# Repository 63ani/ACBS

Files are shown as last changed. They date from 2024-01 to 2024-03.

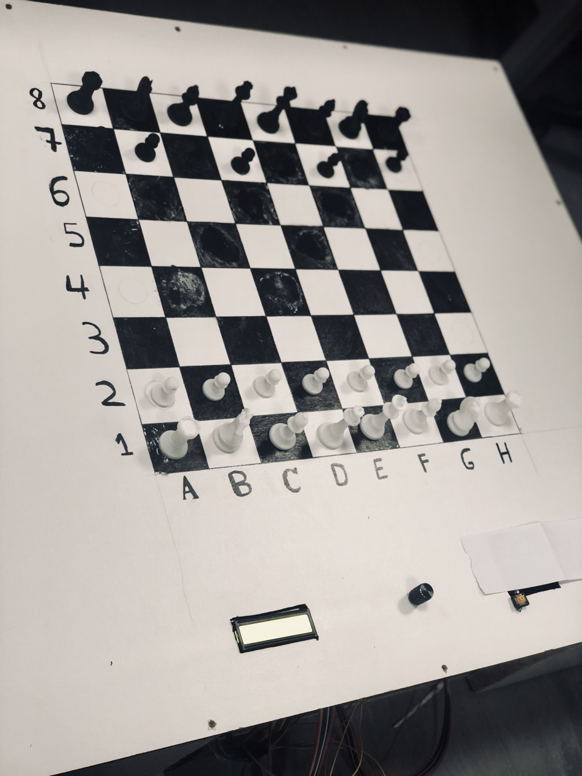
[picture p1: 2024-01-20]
ACBS Picture.jpg

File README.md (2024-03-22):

# Automated Chess Board System (ACBS)

## Introduction

The Automated Chess Board System (ACBS) revolutionizes the classic game of chess, allowing players to engage with an AI opponent while witnessing the game unfold on a physical chessboard. This system cleverly combines traditional chess with modern automation technology, translating digital strategies into physical movements on the chessboard.

## Table of Contents

- [Introduction](#introduction)
- [Theory](#theory)
- [Design](#design)
- [Installation](#installation)
- [Usage](#usage)
- [Contributing](#contributing)

## Theory

ACBS is powered by a valuation-based algorithm with a Minimax core, optimizing moves by evaluating piece values and positions. This sophisticated approach enables dynamic difficulty adjustments, making it suitable for various skill levels.

## Design

Featuring a blend of 3D-printed components and precision engineering, the ACBS design focuses on accuracy and efficiency. It employs NEMA17 stepper motors, DRV8825 drivers, and an ingenious system of limit switches and electromagnets for piece movement.

## Installation

Please refer to the detailed installation instructions provided on our GitHub repository to set up your ACBS.

## Usage

To start playing against the AI or watch the AI play against itself, follow the step-by-step guide on initializing the system and making moves.

## Contributing

We welcome contributions! If you're interested in improving ACBS.

For more detailed information about the Automated Chess Board System, including technical specifications and how to contribute, please contact me.

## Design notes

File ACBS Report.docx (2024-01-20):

Princess Sumaya University for Technology

King Abdullah II Faculty of Engineering

Electrical Engineering Department

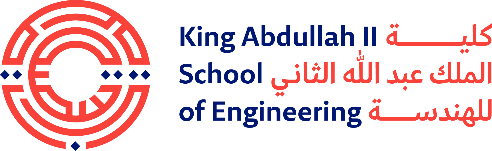
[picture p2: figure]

Embedded Systems 22442

Final Design Project

Automated Chess Board System

Authors: | | | Supervisor:
Laith Taani Osama Alfaqeeh Ahmad Alsayeh | 20200333 20200503 20200997 | Comp. Eng. NIS. NIS. | Dr. Belal Sababha

January 20, 2024

Abstract

The report details the process of designing of an Automated Chess Board System (ACBS) using PIC16F877A microcontroller to allow the interaction between physical chess play and digital strategy computation. The system utilizes stepper motors for piece movement and establishes serial communication for move execution. The programming is carried out in C for the microcontroller and Python for serial interactions. The focus of the investigation was to integrate mechanical components with software to autonomously play chess.

# 1 Introduction

Chess is an ancient strategy game in which you aim to move pieces strategically to defeat your opponents and finally checkmate them. We want to combine the time-tested chess techniques with automation technology with our Automated Chess Board System. Chess players now have a platform to practice and enjoy the game by competing against artificial intelligence (AI). Players may successfully develop their skills and view their strategies play across the board. It transforms commands into movements on an electronic chessboard.

## 1.1 Theory

The system is based on assigning values to pieces and positions to evaluate the best move possible. Each type of piece has a standard value: pawns are worth 1, knights and bishops 3, rooks 5, and queens 9. The king's value is set to 0 since it cannot be captured. The algorithm uses these values to calculate a score for the board at any given state, aiming to maximize the score for one player and minimize it for the other.

The decision-making process in the code uses a simplified version of the Minimax algorithm, selecting moves that lead to the highest possible score for the player while assuming the opponent will play perfectly to minimize that score.

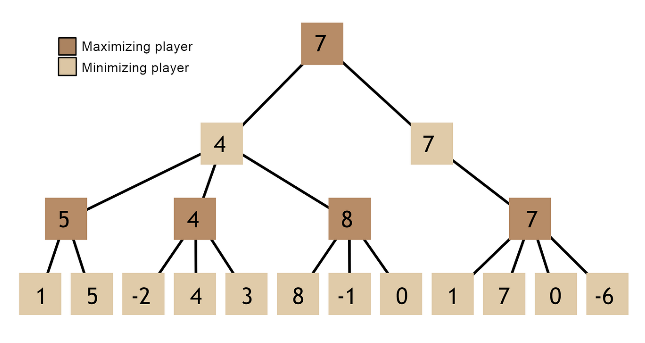
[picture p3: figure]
The Anatomy of a Chess AI. Chess-playing programs made their grand… | by April Walker | Medium

Expressed as: Max(P)=Score(P)-Score(O) , where P is the player and O is the opponent.

The algorithm evaluates all potential moves up to a certain depth and chooses the one with the best score after considering both the material and positional advantages. Changing the depth can be regarded as the level of the chess engine.

Figure 1 Minimax Algorithm

# 2 Design

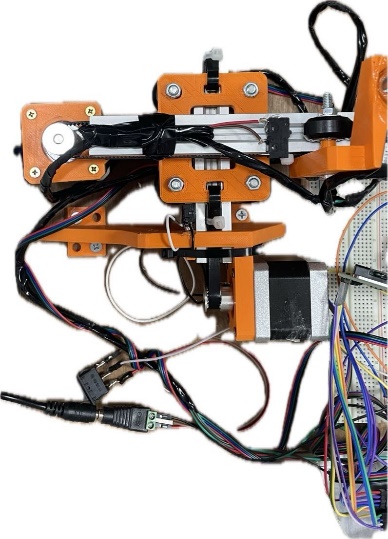
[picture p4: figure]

The design process for the Automated Chess Board System began with a detailed schematic design. This schematic served as a guide, detailing all electronic components and their connections. Then, each component went individual testing to ensure functionality. The NEMA17 stepper motors, were linked to DRV8825 drivers. These motors function by converting a negative edged step signal into precise 1.8-degree rotational movement.

Figure 2 X and Y Axes

The physical structure of the chessboard was then constructed using 3D-printed parts, attached to aluminum profiles and GT belts for the X and Y axes, with careful measurements to determine the correct size of the squares on the board.

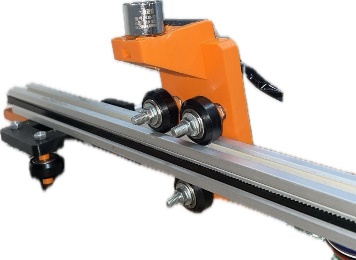
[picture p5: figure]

To ensure precise movements on the chessboard, limit switches were attached to define the 'home' position. Following this, an electromagnet was added for piece manipulation. The electromagnet was attached to a custom 3D-printed part and secured with a screw. Due to the 12V requirement for the electromagnet, it was connected through an NMOS transistor. Further tests were made to calibrate the chessboard, ensuring the movements executed by the electromagnet accurately corresponded to the designated chess squares.

Figure 3 Electromagnet

With the physical components in place, the system's code was developed to interpret and execute chess moves received via serial communication from a Python script. The received data contains information on the type of move and the specific board squares involved. The microcontroller's program was refined to respond accurately to the serial commands, translating them into the precise movements of the chess pieces on the board. This ensured that the Automated Chess Board System could react to the player's strategy as communicated through the Python interface, completing the integration of the hardware and software components.

# 3 Results and Discussions

The design and code for the Automated Chess Board System was functional in the movement of the magnet accurately. Nevertheless, the system's piece movement accuracy was approximately 80%. This was due to the magnet-to-board surface alignment and the variance in chess piece weights. The arrangement of the wiring also presented issues, occasionally disrupting piece movement. The initial code also posed a challenge due to its size (above 2K) which caused us to alter the design, were we had to remove the use of a keypad and depend on serial communication.

Possible fixes to the stated issues could include the use of a servo motor to control the position of the magnet accurately allowing it to be lowered when not needed. Another fix could be the use of a stronger magnet which allows to increase the distance between the magnet and the surface.

# 4 Conclusions

With an astounding 80% accuracy in piece movement, the Automated Chess Board System demonstrates the effective integration of artificial intelligence with mechanical chess. Further improvement is possible, especially in the area of magnet alignment.

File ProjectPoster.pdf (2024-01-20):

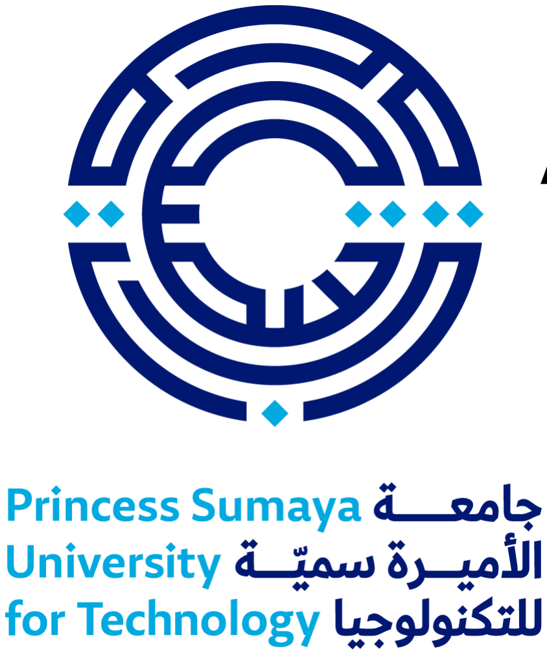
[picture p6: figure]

# Automated Chess Board System

# Introduction

Chess is an ancient strategy game in which you aim to move pieces strategically to defeat your opponents and finally checkmate them. We want to combine the time-tested chess techniques with automation technology with our Automated Chess Board System. Chess players now have a platform to practice and enjoy the game by competing against artificial intelligence (AI). Players may successfully develop their skills and view their strategies play across the board. It transforms commands into movements on an electronic chessboard.

# Design

➢We used two drivers for two motors one on each axis, here’s a schematic for one of the motors

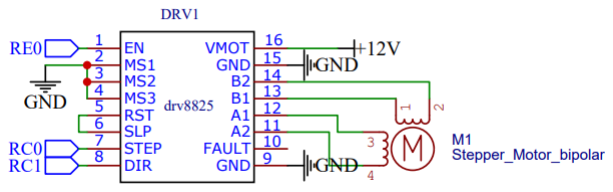
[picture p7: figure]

Figure 1: DRV8825 Driver, Nema 17 stepper motor. The NEMA17 stepper motors, were linked to DRV8825 drivers. These motors function by converting a negative edged step signal into precise 1.8-degree rotational movement.

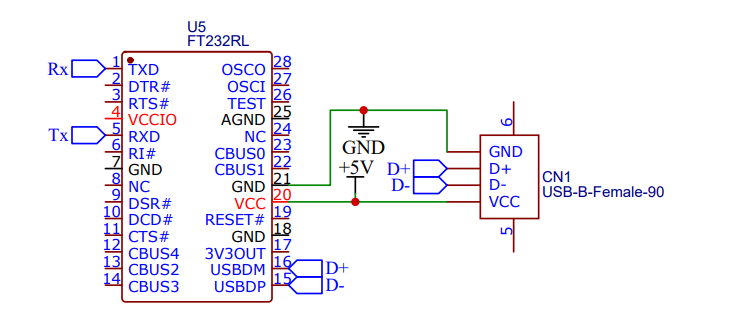
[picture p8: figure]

Figure 2: USB to serial chip DT23RL With the physical components in place, the system's code was developed to interpret and execute chess moves received via serial communication from a Python script. The received data contains information on the type of move and the specific board squares involved. The microcontroller's program was refined to respond accurately to the serial commands, translating them into the precise movements of the chess pieces on the board.

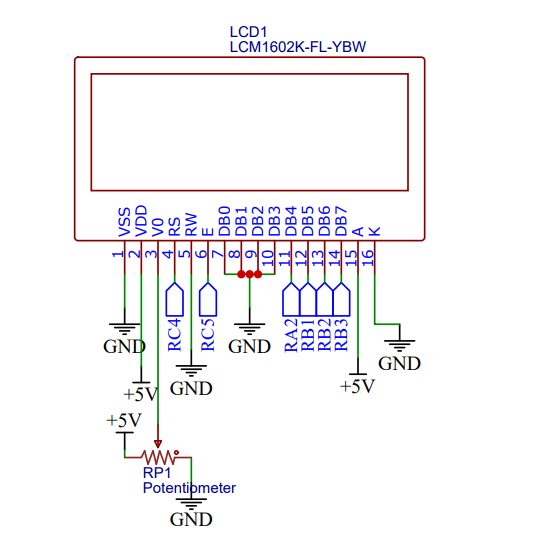
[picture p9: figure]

Figure 3: LCD Screen
The LCD screen provides real-time updates on the game's status, indicating whether it's currently the player's round or the bot's round. It also displays whether the game is in progress or waiting for the user to initiate it. Additionally, the difficulty level is seamlessly controlled through a potentiometer, allowing users to fine-tune the challenge to their preference before starting the game.

# Results

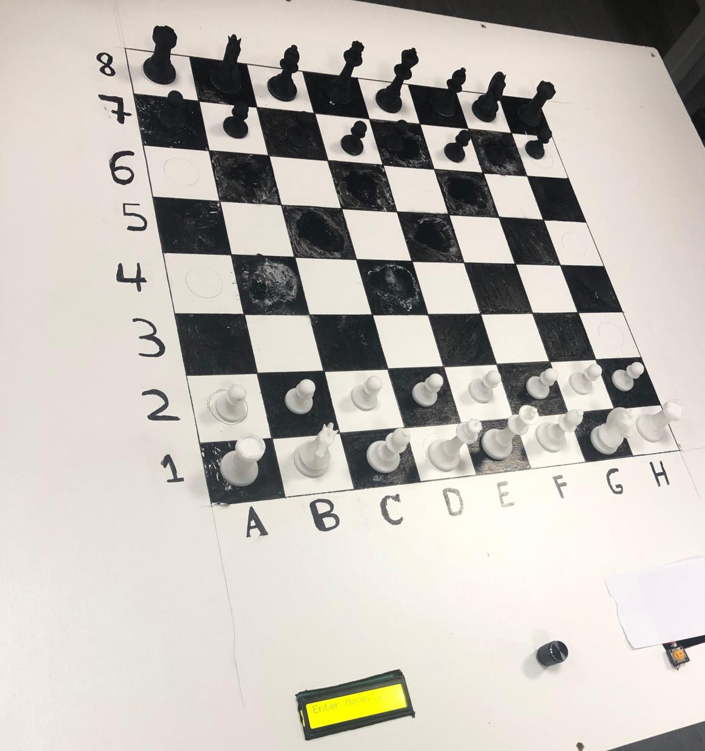
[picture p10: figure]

Figure 4: Chess Board

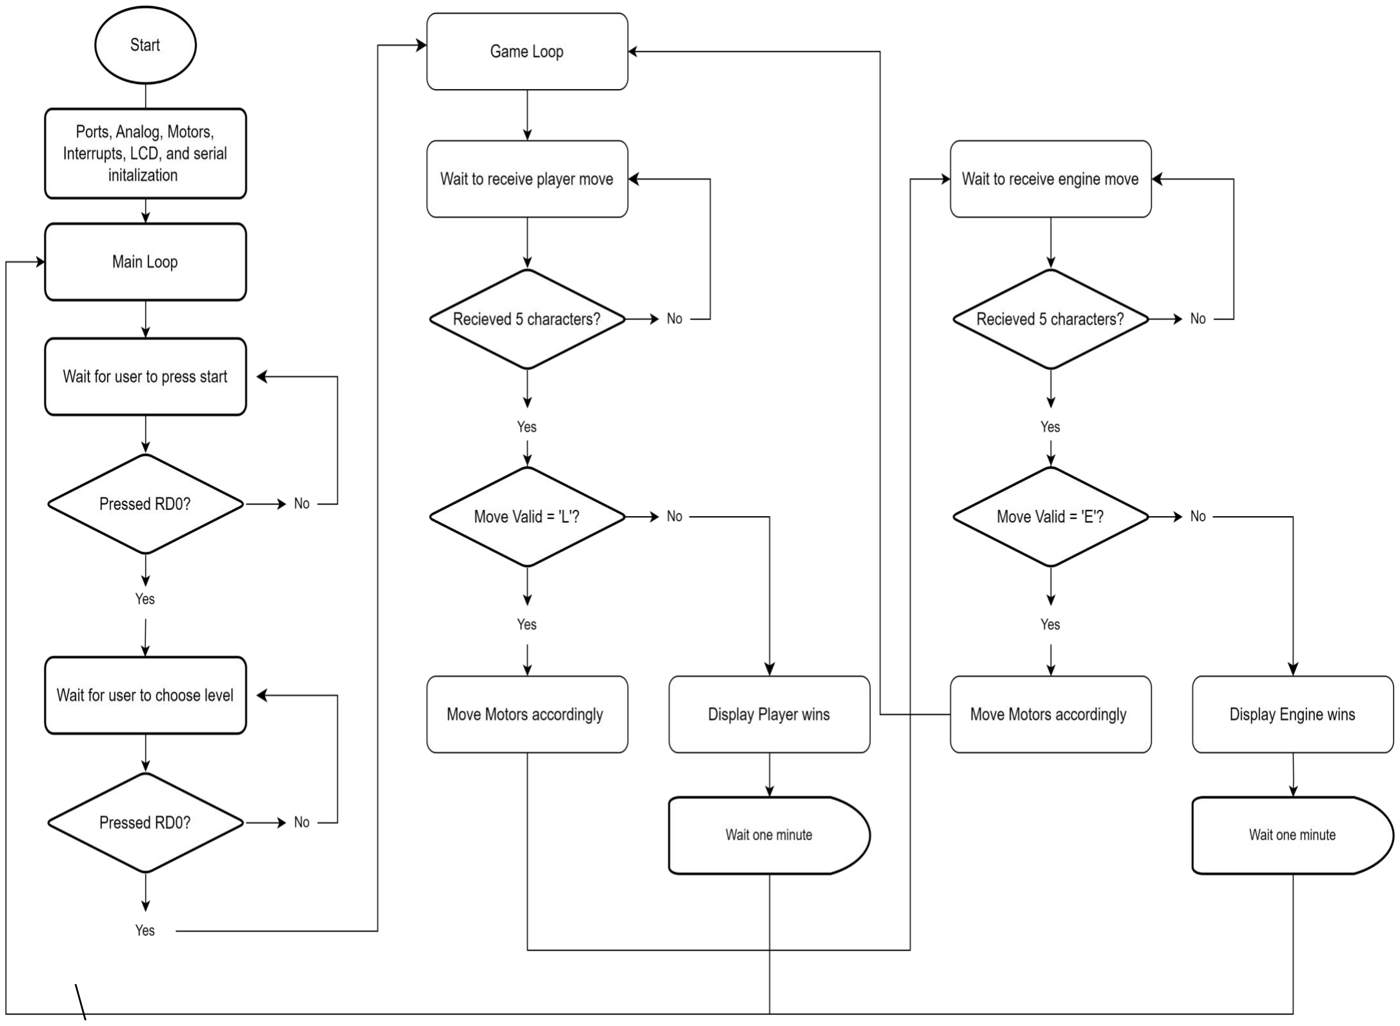
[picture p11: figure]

Figure 5: Software flowchart

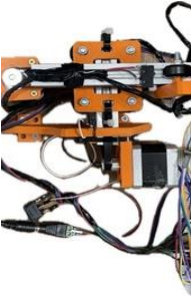
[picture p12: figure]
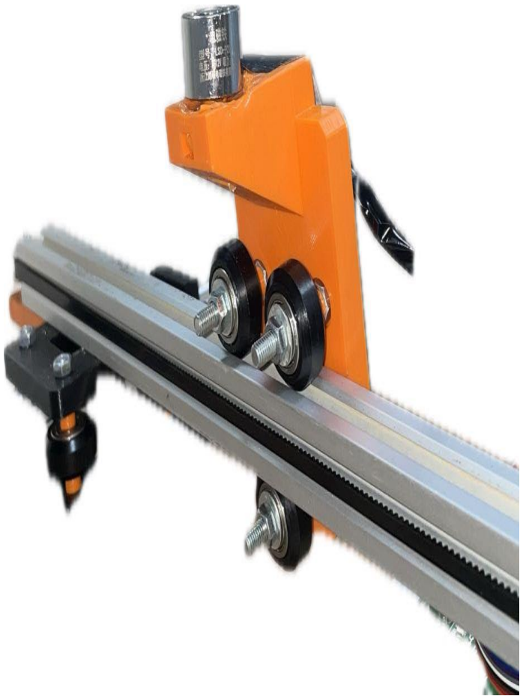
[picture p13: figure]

(a) (b)

Figure 6: (a) ) X and Y Axes , (b) Electromagnet

The physical structure of the chessboard was constructed using 3D-printed parts, attached to aluminum profiles and GT belts for the X and Y axes.
Electromagnet was added for piece manipulation. The electromagnet was attached to a custom 3D-printed part.

# Conclusion

With an astounding 80% accuracy in piece movement, the Automated Chess Board System demonstrates the effective integration of artificial intelligence with mechanical chess. Further improvement is possible, especially in the area of magnet alignment.

## L. Taani, O. Al-Faqeh, A. Al-Sayeh Supervisor: Dr. Belal Sababha Embedded Systems Final Design Project, Fall 2023 King Abdullah II School of Engineering Princess Sumaya University for Technology

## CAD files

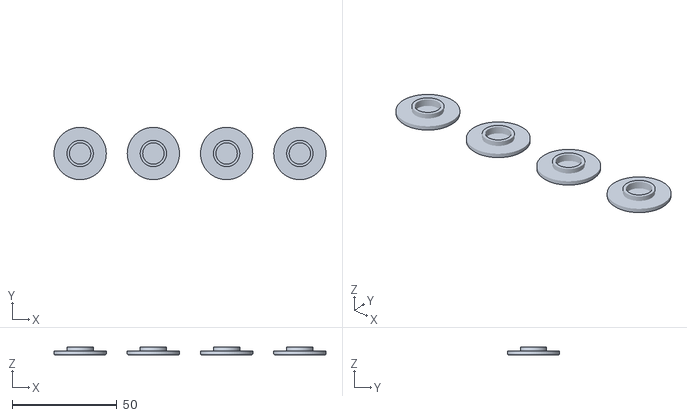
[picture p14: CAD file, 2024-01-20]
3D Prints/_Chess_Pieces15_LG_BASEx4.stl
130.0 x 25.0 x 4.00

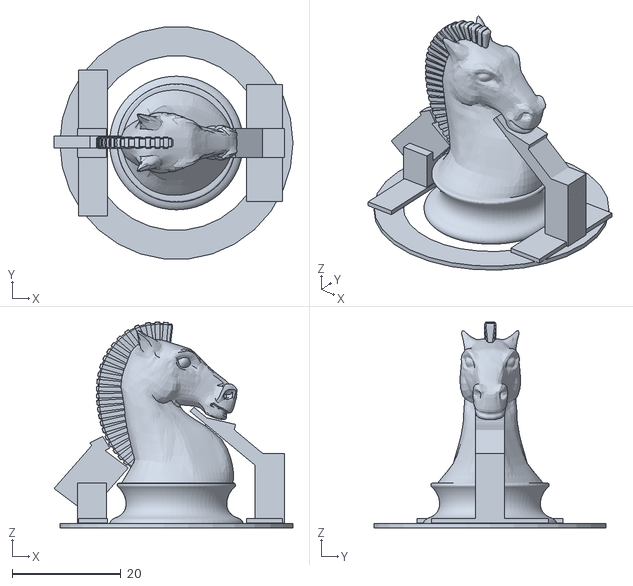
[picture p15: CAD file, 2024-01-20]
3D Prints/_Chess_Pieces15_KNIGHT.stl
43.9 x 42.6 x 37.9

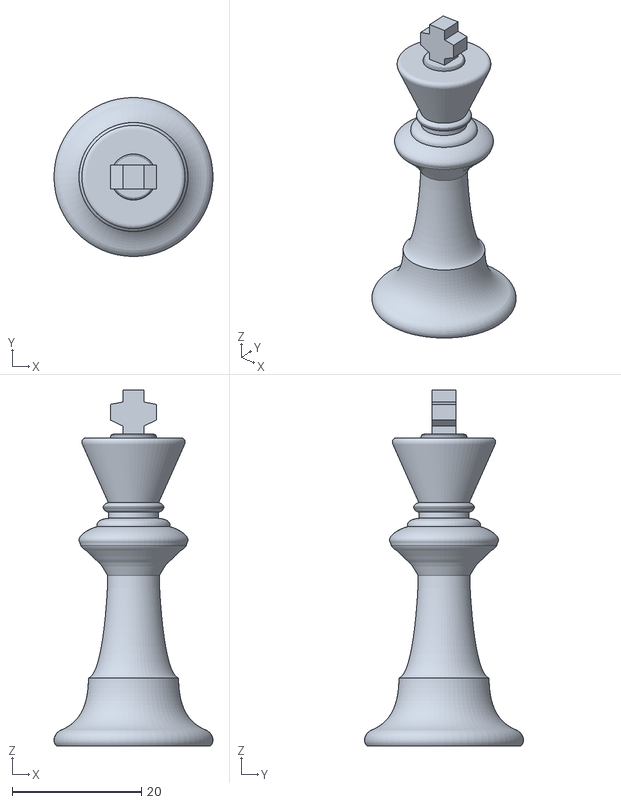
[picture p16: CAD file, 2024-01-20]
3D Prints/_Chess_Pieces15_KING.stl
24.6 x 24.6 x 55.1

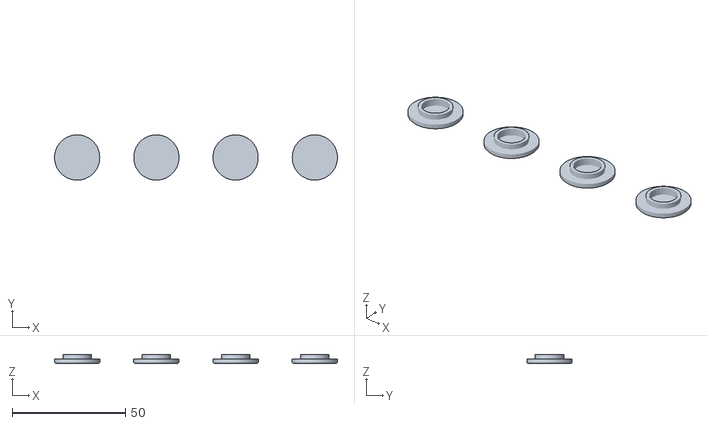
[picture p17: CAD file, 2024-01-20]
3D Prints/_Chess_Pieces15_SM_BASEx4.stl
125.0 x 20.0 x 4.00

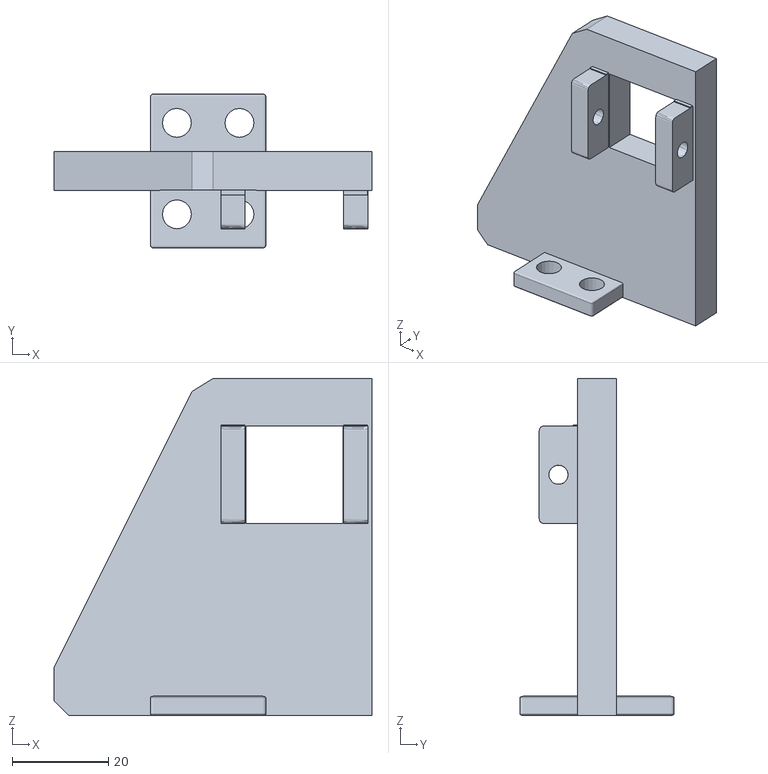
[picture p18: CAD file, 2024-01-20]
3D Prints/side1.stl
66.0 x 32.0 x 70.0

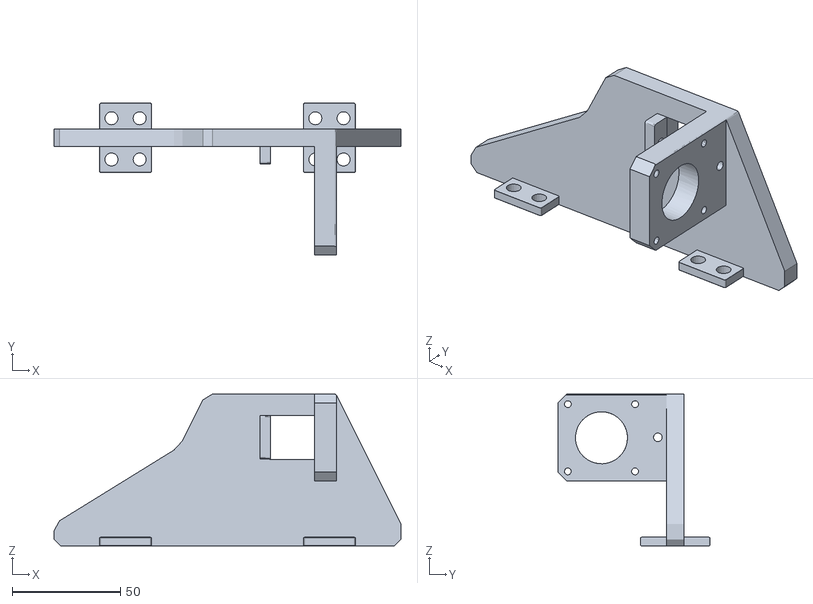
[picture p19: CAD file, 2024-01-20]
3D Prints/Y_axis Motor.stl
160.0 x 70.0 x 70.0

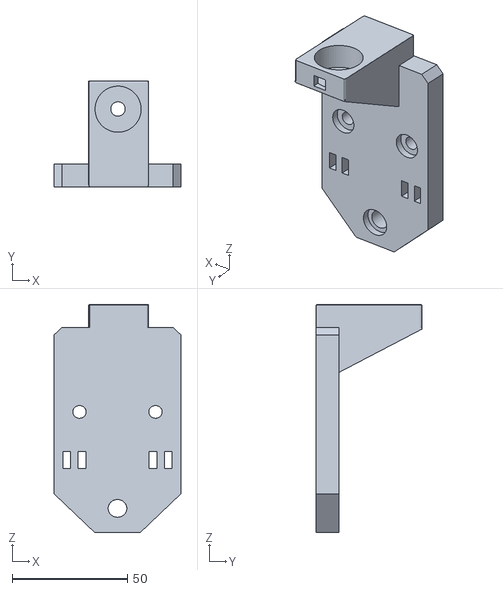
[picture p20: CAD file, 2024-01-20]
3D Prints/magnet.stl
55.0 x 46.0 x 99.0

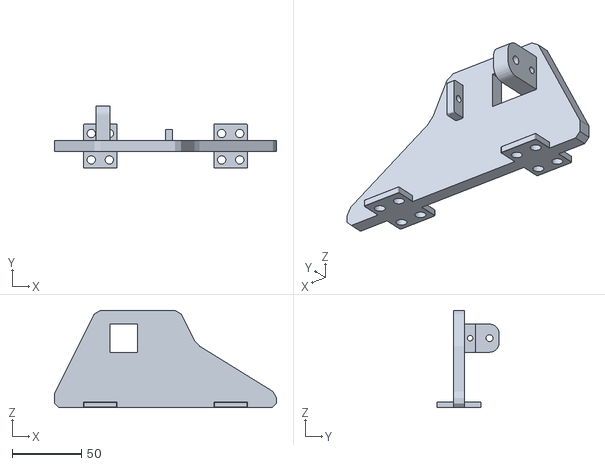
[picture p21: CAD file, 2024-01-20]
3D Prints/Y-axis Side 2.stl
160.0 x 45.0 x 70.0

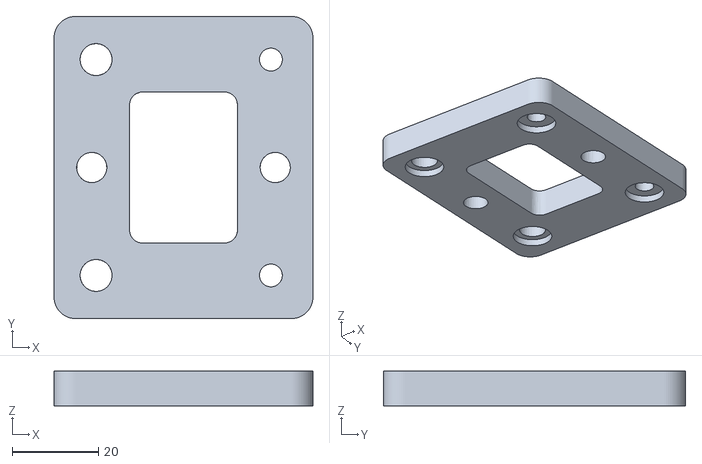
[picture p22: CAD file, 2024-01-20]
3D Prints/Bottom plate.stl
60.0 x 70.0 x 8.00

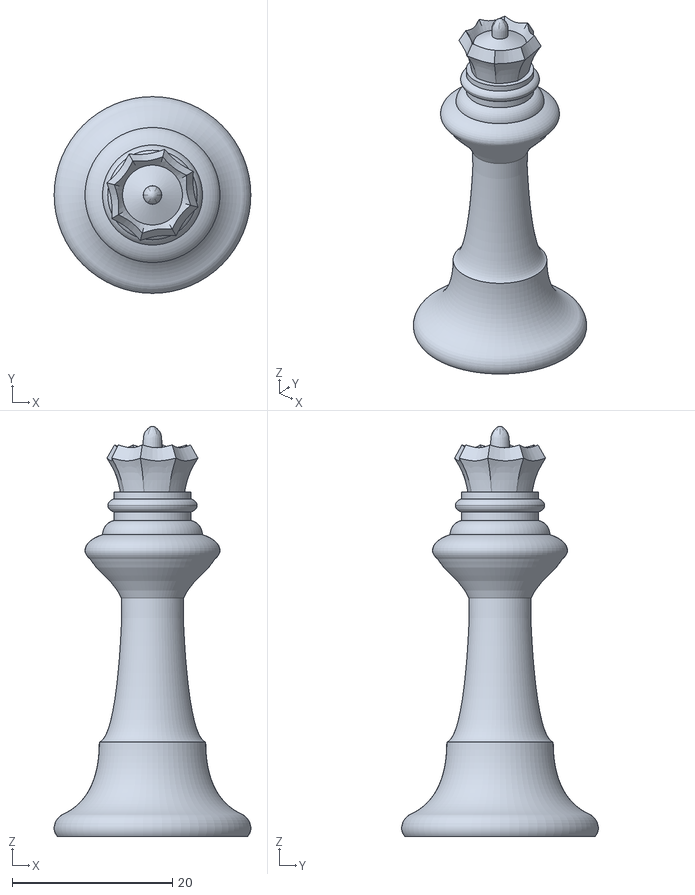
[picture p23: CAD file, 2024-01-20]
3D Prints/_Chess_Pieces15_QUEEN.stl
24.6 x 24.6 x 51.2

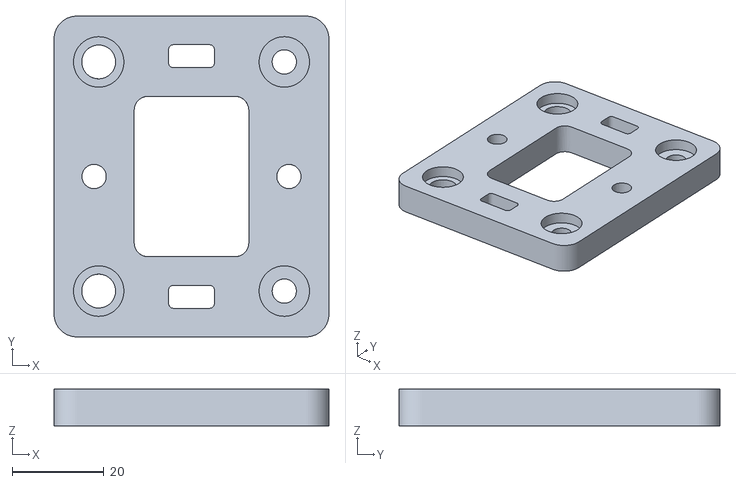
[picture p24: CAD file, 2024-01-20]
3D Prints/Top plate.stl
60.0 x 70.0 x 8.00

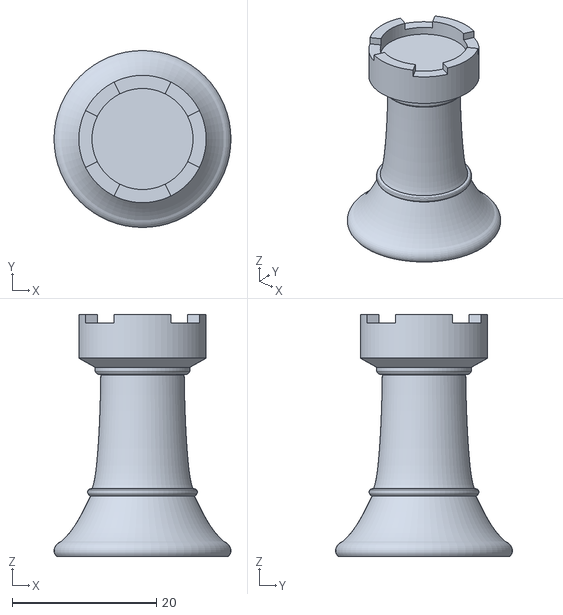
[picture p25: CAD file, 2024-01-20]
3D Prints/_Chess_Pieces15_ROOK_plain.stl
24.5 x 24.5 x 33.6

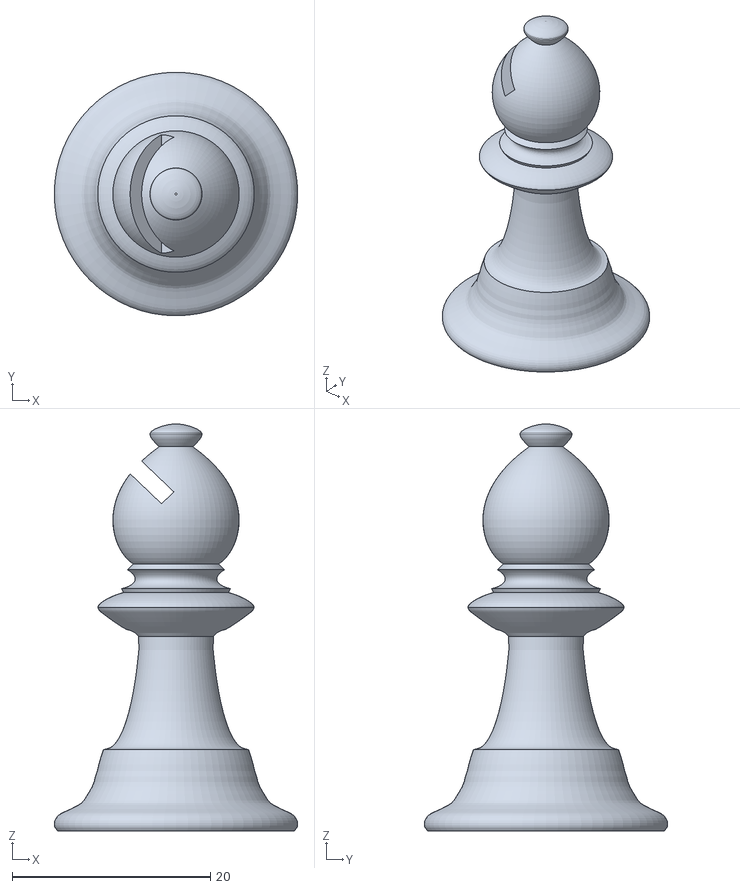
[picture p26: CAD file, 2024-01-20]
3D Prints/_Chess_Pieces15_BISHOP.stl
24.6 x 24.6 x 41.1

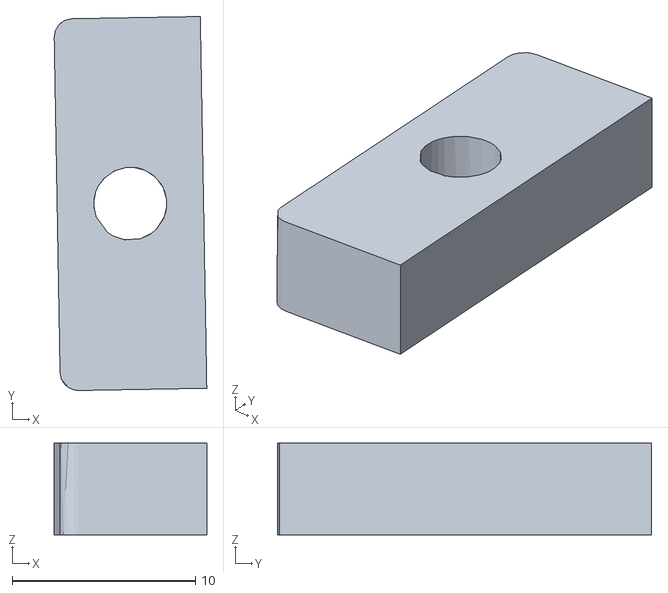
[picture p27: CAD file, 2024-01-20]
3D Prints/Mini piece.stl
8.33 x 20.4 x 5.00

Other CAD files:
3D Prints/side2.stl
3D Prints/x_plate.stl
3D Prints/_Chess_Pieces15_PAWN.stl
3D Prints/spacer.stl

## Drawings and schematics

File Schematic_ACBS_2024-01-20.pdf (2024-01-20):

RA2

RB1

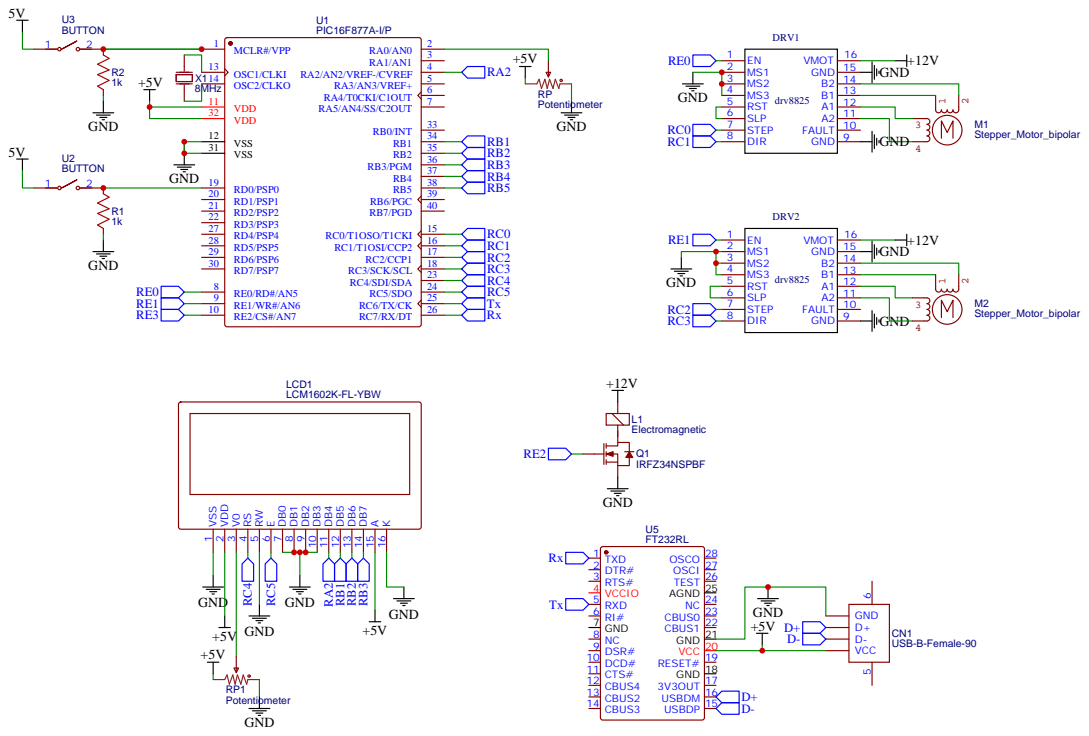
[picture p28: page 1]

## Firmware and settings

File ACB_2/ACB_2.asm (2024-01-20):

_interrupt:
	MOVWF      R15+0
	SWAPF      STATUS+0, 0
	CLRF       STATUS+0
	MOVWF      ___saveSTATUS+0
	MOVF       PCLATH+0, 0
	MOVWF      ___savePCLATH+0
	CLRF       PCLATH+0

;ACB_2.c,50 :: 		void interrupt(void) {
;ACB_2.c,51 :: 		if (INTCON & 0x01) {      // PORTB Change interrupt
	BTFSS      INTCON+0, 0
	GOTO       L_interrupt0
;ACB_2.c,52 :: 		if (PORTB & 0x10)       // X_Limit = 1
	BTFSS      PORTB+0, 4
	GOTO       L_interrupt1
;ACB_2.c,53 :: 		PORTE = PORTE | 0x01; // Turn off X axis motor
	BSF        PORTE+0, 0
	GOTO       L_interrupt2
L_interrupt1:
;ACB_2.c,54 :: 		else if (PORTB & 0x20)  // Y_Limit = 1
	BTFSS      PORTB+0, 5
	GOTO       L_interrupt3
;ACB_2.c,55 :: 		PORTE = PORTE | 0x02; // Turn off Y axis motor
	BSF        PORTE+0, 1
L_interrupt3:
L_interrupt2:
;ACB_2.c,57 :: 		INTCON = INTCON & 0xFE; // Clear RBIF
	MOVLW      254
	ANDWF      INTCON+0, 1
;ACB_2.c,58 :: 		} else if (PIR1 & 0x20) { // Received data
	GOTO       L_interrupt4
L_interrupt0:
	BTFSS      PIR1+0, 5
	GOTO       L_interrupt5
;ACB_2.c,59 :: 		myRxBuffer[Rx_count] = RCREG;
	MOVF       _Rx_count+0, 0
	ADDLW      _myRxBuffer+0
	MOVWF      FSR
	MOVF       RCREG+0, 0
	MOVWF      INDF+0
;ACB_2.c,60 :: 		Rx_count++;
	INCF       _Rx_count+0, 1
;ACB_2.c,61 :: 		PIR1 = PIR1 & 0xDF;       // Clear RCIF
	MOVLW      223
	ANDWF      PIR1+0, 1
;ACB_2.c,62 :: 		} else if (INTCON & 0x04) { // TMRO overflow
	GOTO       L_interrupt6
L_interrupt5:
	BTFSS      INTCON+0, 2
	GOTO       L_interrupt7
;ACB_2.c,63 :: 		TMR0 = 248;
	MOVLW      248
	MOVWF      TMR0+0
;ACB_2.c,64 :: 		tick++;
	INCF       _tick+0, 1
	BTFSC      STATUS+0, 2
	INCF       _tick+1, 1
;ACB_2.c,65 :: 		INTCON = INTCON & 0xFB;
	MOVLW      251
	ANDWF      INTCON+0, 1
;ACB_2.c,66 :: 		}
L_interrupt7:
L_interrupt6:
L_interrupt4:
;ACB_2.c,67 :: 		}
L_end_interrupt:
L__interrupt117:
	MOVF       ___savePCLATH+0, 0
	MOVWF      PCLATH+0
	SWAPF      ___saveSTATUS+0, 0
	MOVWF      STATUS+0
	SWAPF      R15+0, 1
	SWAPF      R15+0, 0
	RETFIE
; end of _interrupt

_main:

;ACB_2.c,69 :: 		void main() {
;ACB_2.c,70 :: 		ADCON0 = 0x41;// ATD ON, Don't GO, Channel 0, Fosc/16
	MOVLW      65
	MOVWF      ADCON0+0
;ACB_2.c,71 :: 		ADCON1 = 0x4E;// A0  Analog, 500 KHz, left justified
	MOVLW      78
	MOVWF      ADCON1+0
;ACB_2.c,72 :: 		TRISA = 0x01;  // RA2 = D1 (LCD), RA0 = Analog input (Potentiometer)
	MOVLW      1
	MOVWF      TRISA+0
;ACB_2.c,73 :: 		TRISB = 0x30;  // RB1-RB3 = D2-D4, RB4 = Switch_X, RB5 = Switch_Y, RB6 and RB7
	MOVLW      48
	MOVWF      TRISB+0
;ACB_2.c,75 :: 		TRISC = 0x80;  // RC0 = Step_X, RC1 = Dir_X, RC2 = Step_Y, RC3 = Dir_Y, RC4 =
	MOVLW      128
	MOVWF      TRISC+0
;ACB_2.c,77 :: 		TRISD = 0x01; // RD0 = Push button
	MOVLW      1
	MOVWF      TRISD+0
;ACB_2.c,78 :: 		TRISE = 0x00; // RE0 = EN_X, RE1 = EN_Y (active low), RE2 = Magnet
	CLRF       TRISE+0
;ACB_2.c,80 :: 		PORTC = 0x00;
	CLRF       PORTC+0
;ACB_2.c,81 :: 		PORTE = 0x03;  // Motors OFF
	MOVLW      3
	MOVWF      PORTE+0
;ACB_2.c,82 :: 		INTCON = 0xE8; // GIE, RBIE, PEIE, and TMR0IE
	MOVLW      232
	MOVWF      INTCON+0
;ACB_2.c,83 :: 		OPTION_REG = 0x87;
	MOVLW      135
	MOVWF      OPTION_REG+0
;ACB_2.c,84 :: 		TMR0 = 248;
	MOVLW      248
	MOVWF      TMR0+0
;ACB_2.c,87 :: 		Lcd_Init();
	CALL       _Lcd_Init+0
;ACB_2.c,88 :: 		USART_Init();
	CALL       _USART_Init+0
;ACB_2.c,89 :: 		Lcd_Cmd(_LCD_CLEAR);      // Clear display
	MOVLW      1
	MOVWF      FARG_Lcd_Cmd_out_char+0
	CALL       _Lcd_Cmd+0
;ACB_2.c,90 :: 		Lcd_Cmd(_LCD_CURSOR_OFF); // Cursor off
	MOVLW      12
	MOVWF      FARG_Lcd_Cmd_out_char+0
	CALL       _Lcd_Cmd+0
;ACB_2.c,91 :: 		Move_Home();
	CALL       _Move_Home+0
;ACB_2.c,92 :: 		Rx_count = 0;
	CLRF       _Rx_count+0
;ACB_2.c,93 :: 		while (1) {
L_main8:
;ACB_2.c,94 :: 		Lcd_Cmd(_LCD_CLEAR);
	MOVLW      1
	MOVWF      FARG_Lcd_Cmd_out_char+0
	CALL       _Lcd_Cmd+0
;ACB_2.c,95 :: 		Lcd_Out(1, 1, "Welcome to ACBS");
	MOVLW      1
	MOVWF      FARG_Lcd_Out_row+0
	MOVLW      1
	MOVWF      FARG_Lcd_Out_column+0
	MOVLW      ?lstr1_ACB_2+0
	MOVWF      FARG_Lcd_Out_text+0
	CALL       _Lcd_Out+0
;ACB_2.c,96 :: 		Lcd_Out(2, 1, "Start?");
	MOVLW      2
	MOVWF      FARG_Lcd_Out_row+0
	MOVLW      1
	MOVWF      FARG_Lcd_Out_column+0
	MOVLW      ?lstr2_ACB_2+0
	MOVWF      FARG_Lcd_Out_text+0
	CALL       _Lcd_Out+0
;ACB_2.c,98 :: 		while (!(PORTD & 0x01));
L_main10:
	BTFSC      PORTD+0, 0
	GOTO       L_main11
	GOTO       L_main10
L_main11:
;ACB_2.c,99 :: 		USART_Tx('S');
	MOVLW      83
	MOVWF      FARG_USART_Tx_trans+0
	CALL       _USART_Tx+0
;ACB_2.c,101 :: 		msDelay(200);
	MOVLW      200
	MOVWF      FARG_msDelay_ms+0
	CLRF       FARG_msDelay_ms+1
	CALL       _msDelay+0
;ACB_2.c,102 :: 		level = read_level();
	CALL       _read_level+0
	MOVF       R0+0, 0
	MOVWF      _level+0
;ACB_2.c,103 :: 		USART_TX(level+'0');
	MOVLW      48
	ADDWF      R0+0, 0
	MOVWF      FARG_USART_Tx_trans+0
	CALL       _USART_Tx+0
;ACB_2.c,105 :: 		Lcd_Cmd(_LCD_CLEAR);
	MOVLW      1
	MOVWF      FARG_Lcd_Cmd_out_char+0
	CALL       _Lcd_Cmd+0
;ACB_2.c,106 :: 		Lcd_Out(1, 1, "Game On");
	MOVLW      1
	MOVWF      FARG_Lcd_Out_row+0
	MOVLW      1
	MOVWF      FARG_Lcd_Out_column+0
	MOVLW      ?lstr3_ACB_2+0
	MOVWF      FARG_Lcd_Out_text+0
	CALL       _Lcd_Out+0
;ACB_2.c,107 :: 		game = 1;
	MOVLW      1
	MOVWF      _game+0
;ACB_2.c,110 :: 		do { // Game is on
L_main12:
;ACB_2.c,111 :: 		Lcd_Cmd(_LCD_CLEAR);
	MOVLW      1
	MOVWF      FARG_Lcd_Cmd_out_char+0
	CALL       _Lcd_Cmd+0
;ACB_2.c,112 :: 		Lcd_Out(1, 1, "Enter Move...");
	MOVLW      1
	MOVWF      FARG_Lcd_Out_row+0
	MOVLW      1
	MOVWF      FARG_Lcd_Out_column+0
	MOVLW      ?lstr4_ACB_2+0
	MOVWF      FARG_Lcd_Out_text+0
	CALL       _Lcd_Out+0
;ACB_2.c,113 :: 		Rx_Count = 0;
	CLRF       _Rx_count+0
;ACB_2.c,114 :: 		while (Rx_count != 6);           // Wait for recieval of the Move
L_main15:
	MOVF       _Rx_count+0, 0
	XORLW      6
	BTFSC      STATUS+0, 2
	GOTO       L_main16
	GOTO       L_main15
L_main16:
;ACB_2.c,115 :: 		Rx_count = 0; // Reset rx counter
	CLRF       _Rx_count+0
;ACB_2.c,116 :: 		Move_Valid = myRXBuffer[0];
	MOVF       _myRxBuffer+0, 0
	MOVWF      _Move_Valid+0
;ACB_2.c,117 :: 		startx = myRxBuffer[1];
	MOVF       _myRxBuffer+1, 0
	MOVWF      _startx+0
;ACB_2.c,118 :: 		starty = myRxBuffer[2];
	MOVF       _myRxBuffer+2, 0
	MOVWF      _starty+0
;ACB_2.c,119 :: 		Move_Type = myRxBuffer[3];
	MOVF       _myRxBuffer+3, 0
	MOVWF      _Move_Type+0
;ACB_2.c,120 :: 		endx = myRxBuffer[4];
	MOVF       _myRxBuffer+4, 0
	MOVWF      _endx+0
;ACB_2.c,121 :: 		endy = myRxbuffer[5];
	MOVF       _myRxBuffer+5, 0
	MOVWF      _endy+0
;ACB_2.c,123 :: 		if (Move_Valid == 'L') { // Move is legal
	MOVF       _myRxBuffer+0, 0
	XORLW      76
	BTFSS      STATUS+0, 2
	GOTO       L_main17
;ACB_2.c,124 :: 		Lcd_Cmd(_LCD_CLEAR);
	MOVLW      1
	MOVWF      FARG_Lcd_Cmd_out_char+0
	CALL       _Lcd_Cmd+0
;ACB_2.c,125 :: 		Lcd_Out(1, 1, "Player Moving...");
	MOVLW      1
	MOVWF      FARG_Lcd_Out_row+0
	MOVLW      1
	MOVWF      FARG_Lcd_Out_column+0
	MOVLW      ?lstr5_ACB_2+0
	MOVWF      FARG_Lcd_Out_text+0
	CALL       _Lcd_Out+0
;ACB_2.c,126 :: 		Move_motors();
	CALL       _Move_motors+0
;ACB_2.c,127 :: 		USART_Tx('D');
	MOVLW      68
	MOVWF      FARG_USART_Tx_trans+0
	CALL       _USART_Tx+0
;ACB_2.c,128 :: 		}
	GOTO       L_main18
L_main17:
;ACB_2.c,130 :: 		else if (Move_Valid == 'M') {
	MOVF       _Move_Valid+0, 0
	XORLW      77
	BTFSS      STATUS+0, 2
	GOTO       L_main19
;ACB_2.c,132 :: 		Lcd_Cmd(_LCD_CLEAR);
	MOVLW      1
	MOVWF      FARG_Lcd_Cmd_out_char+0
	CALL       _Lcd_Cmd+0
;ACB_2.c,133 :: 		Lcd_Out(1, 1, "Game ended");
	MOVLW      1
	MOVWF      FARG_Lcd_Out_row+0
	MOVLW      1
	MOVWF      FARG_Lcd_Out_column+0
	MOVLW      ?lstr6_ACB_2+0
	MOVWF      FARG_Lcd_Out_text+0
	CALL       _Lcd_Out+0
;ACB_2.c,134 :: 		Lcd_Out(2, 1, "Player wins");
	MOVLW      2
	MOVWF      FARG_Lcd_Out_row+0
	MOVLW      1
	MOVWF      FARG_Lcd_Out_column+0
	MOVLW      ?lstr7_ACB_2+0
	MOVWF      FARG_Lcd_Out_text+0
	CALL       _Lcd_Out+0
;ACB_2.c,135 :: 		game = 0;
	CLRF       _game+0
;ACB_2.c,136 :: 		break;
	GOTO       L_main13
;ACB_2.c,137 :: 		}
L_main19:
L_main18:
;ACB_2.c,138 :: 		Rx_Count = 0;
	CLRF       _Rx_count+0
;ACB_2.c,139 :: 		while (Rx_count != 6);           // Wait to recieve engine move
L_main20:
	MOVF       _Rx_count+0, 0
	XORLW      6
	BTFSC      STATUS+0, 2
	GOTO       L_main21
	GOTO       L_main20
L_main21:
;ACB_2.c,140 :: 		Rx_count = 0; // reset counter
	CLRF       _Rx_count+0
;ACB_2.c,141 :: 		Move_Valid = myRXBuffer[0];
	MOVF       _myRxBuffer+0, 0
	MOVWF      _Move_Valid+0
;ACB_2.c,142 :: 		startx = myRxBuffer[1];
	MOVF       _myRxBuffer+1, 0
	MOVWF      _startx+0
;ACB_2.c,143 :: 		starty = myRxBuffer[2];
	MOVF       _myRxBuffer+2, 0
	MOVWF      _starty+0
;ACB_2.c,144 :: 		Move_Type = myRxBuffer[3];
	MOVF       _myRxBuffer+3, 0
	MOVWF      _Move_Type+0
;ACB_2.c,145 :: 		endx = myRxBuffer[4];
	MOVF       _myRxBuffer+4, 0
	MOVWF      _endx+0
;ACB_2.c,146 :: 		endy = myRxbuffer[5];
	MOVF       _myRxBuffer+5, 0
	MOVWF      _endy+0
;ACB_2.c,148 :: 		if (Move_Valid == 'E'){
	MOVF       _myRxBuffer+0, 0
	XORLW      69
	BTFSS      STATUS+0, 2
	GOTO       L_main22
;ACB_2.c,149 :: 		Lcd_Cmd(_LCD_CLEAR);
	MOVLW      1
	MOVWF      FARG_Lcd_Cmd_out_char+0
	CALL       _Lcd_Cmd+0
;ACB_2.c,150 :: 		Lcd_Out(1, 1, "Engine Moving...");
	MOVLW      1
	MOVWF      FARG_Lcd_Out_row+0
	MOVLW      1
	MOVWF      FARG_Lcd_Out_column+0
	MOVLW      ?lstr8_ACB_2+0
	MOVWF      FARG_Lcd_Out_text+0
	CALL       _Lcd_Out+0
;ACB_2.c,151 :: 		Move_motors();
	CALL       _Move_motors+0
;ACB_2.c,152 :: 		USART_Tx('D');
	MOVLW      68
	MOVWF      FARG_USART_Tx_trans+0
	CALL       _USART_Tx+0
;ACB_2.c,153 :: 		}
	GOTO       L_main23
L_main22:
;ACB_2.c,155 :: 		else if (Move_Valid == 'M') {
	MOVF       _Move_Valid+0, 0
	XORLW      77
	BTFSS      STATUS+0, 2
	GOTO       L_main24
;ACB_2.c,157 :: 		Lcd_Cmd(_LCD_CLEAR);
	MOVLW      1
	MOVWF      FARG_Lcd_Cmd_out_char+0
	CALL       _Lcd_Cmd+0
;ACB_2.c,158 :: 		Lcd_Out(1, 1, "Game ended");
	MOVLW      1
	MOVWF      FARG_Lcd_Out_row+0
	MOVLW      1
	MOVWF      FARG_Lcd_Out_column+0
	MOVLW      ?lstr9_ACB_2+0
	MOVWF      FARG_Lcd_Out_text+0
	CALL       _Lcd_Out+0
;ACB_2.c,159 :: 		Lcd_Out(2, 1, "Engine wins");
	MOVLW      2
	MOVWF      FARG_Lcd_Out_row+0
	MOVLW      1
	MOVWF      FARG_Lcd_Out_column+0
	MOVLW      ?lstr10_ACB_2+0
	MOVWF      FARG_Lcd_Out_text+0
	CALL       _Lcd_Out+0
;ACB_2.c,160 :: 		game = 0;
	CLRF       _game+0
;ACB_2.c,161 :: 		break;
	GOTO       L_main13
;ACB_2.c,162 :: 		}
L_main24:
L_main23:
;ACB_2.c,163 :: 		} while (game);
	MOVF       _game+0, 0
	BTFSS      STATUS+0, 2
	GOTO       L_main12
L_main13:
;ACB_2.c,164 :: 		msDelay(60000); // Wait one minute
	MOVLW      96
	MOVWF      FARG_msDelay_ms+0
	MOVLW      234
	MOVWF      FARG_msDelay_ms+1
	CALL       _msDelay+0
;ACB_2.c,165 :: 		}
	GOTO       L_main8
;ACB_2.c,166 :: 		}
L_end_main:
	GOTO       $+0
; end of _main

_msDelay:

;ACB_2.c,168 :: 		void msDelay(unsigned int ms) {
;ACB_2.c,169 :: 		tick = 0;
	CLRF       _tick+0
	CLRF       _tick+1
;ACB_2.c,170 :: 		while (tick < ms)
L_msDelay25:
	MOVF       FARG_msDelay_ms+1, 0
	SUBWF      _tick+1, 0
	BTFSS      STATUS+0, 2
	GOTO       L__msDelay120
	MOVF       FARG_msDelay_ms+0, 0
	SUBWF      _tick+0, 0
L__msDelay120:
	BTFSC      STATUS+0, 0
	GOTO       L_msDelay26
;ACB_2.c,171 :: 		;
	GOTO       L_msDelay25
L_msDelay26:
;ACB_2.c,172 :: 		}
L_end_msDelay:
	RETURN
; end of _msDelay

_MotorDelay:

;ACB_2.c,174 :: 		void MotorDelay() {
;ACB_2.c,175 :: 		for (a = 0; a < 200; a++)
	CLRF       _a+0
L_MotorDelay27:
	MOVLW      200
	SUBWF      _a+0, 0
	BTFSC      STATUS+0, 0
	GOTO       L_MotorDelay28
	INCF       _a+0, 1
;ACB_2.c,176 :: 		;
	GOTO       L_MotorDelay27
L_MotorDelay28:
;ACB_2.c,177 :: 		}
L_end_MotorDelay:
	RETURN
; end of _MotorDelay

_Move_X:

;ACB_2.c,180 :: 		void Move_X(unsigned char dir, unsigned int steps) {
;ACB_2.c,182 :: 		if (dir)
	MOVF       FARG_Move_X_dir+0, 0
	BTFSC      STATUS+0, 2
	GOTO       L_Move_X30
;ACB_2.c,183 :: 		PORTC = 0x02; // Dir_X (RC1) = 1 (right)
	MOVLW      2
	MOVWF      PORTC+0
	GOTO       L_Move_X31
L_Move_X30:
;ACB_2.c,185 :: 		PORTC = 0x00; // Dir_X (RC1) = 0 (left)
	CLRF       PORTC+0
L_Move_X31:
;ACB_2.c,187 :: 		PORTE = PORTE & 0xFE; // EN_X (RE0) = 0 (Enable X motor)
	MOVLW      254
	ANDWF      PORTE+0, 1
;ACB_2.c,189 :: 		for (j = 0; j < steps; j++) {
	CLRF       Move_X_j_L0+0
	CLRF       Move_X_j_L0+1
L_Move_X32:
	MOVF       FARG_Move_X_steps+1, 0
	SUBWF      Move_X_j_L0+1, 0
	BTFSS      STATUS+0, 2
	GOTO       L__Move_X123
	MOVF       FARG_Move_X_steps+0, 0
	SUBWF      Move_X_j_L0+0, 0
L__Move_X123:
	BTFSC      STATUS+0, 0
	GOTO       L_Move_X33
;ACB_2.c,190 :: 		PORTC = PORTC & 0xFE; // Step_X (RC0) = 0
	MOVLW      254
	ANDWF      PORTC+0, 1
;ACB_2.c,191 :: 		MotorDelay();
	CALL       _MotorDelay+0
;ACB_2.c,192 :: 		PORTC = PORTC | 0x01; // Step_X (RC0) = 1
	BSF        PORTC+0, 0
;ACB_2.c,193 :: 		MotorDelay();
	CALL       _MotorDelay+0
;ACB_2.c,189 :: 		for (j = 0; j < steps; j++) {
	INCF       Move_X_j_L0+0, 1
	BTFSC      STATUS+0, 2
	INCF       Move_X_j_L0+1, 1
;ACB_2.c,194 :: 		}
	GOTO       L_Move_X32
L_Move_X33:
;ACB_2.c,196 :: 		PORTE = PORTE | 0x03; // Disable all motors
	MOVLW      3
	IORWF      PORTE+0, 1
;ACB_2.c,197 :: 		}
L_end_Move_X:
	RETURN
; end of _Move_X

_Move_Y:

;ACB_2.c,199 :: 		void Move_Y(unsigned char dir, unsigned int steps) {
;ACB_2.c,201 :: 		if (dir)
	MOVF       FARG_Move_Y_dir+0, 0
	BTFSC      STATUS+0, 2
	GOTO       L_Move_Y35
;ACB_2.c,202 :: 		PORTC = 0x08; // Dir_Y (RC3) = 1 (up)
	MOVLW      8
	MOVWF      PORTC+0
	GOTO       L_Move_Y36
L_Move_Y35:
;ACB_2.c,204 :: 		PORTC = 0x00; // Dir_Y (RC3) = 0 (down)
	CLRF       PORTC+0
L_Move_Y36:
;ACB_2.c,206 :: 		PORTE = PORTE & 0xFD; // EN_Y (RE1) = 0 (Enable Y motor)
	MOVLW      253
	ANDWF      PORTE+0, 1
;ACB_2.c,208 :: 		for (j = 0; j < steps; j++) {
	CLRF       Move_Y_j_L0+0
	CLRF       Move_Y_j_L0+1
L_Move_Y37:
	MOVF       FARG_Move_Y_steps+1, 0
	SUBWF      Move_Y_j_L0+1, 0
	BTFSS      STATUS+0, 2
	GOTO       L__Move_Y125
	MOVF       FARG_Move_Y_steps+0, 0
	SUBWF      Move_Y_j_L0+0, 0
L__Move_Y125:
	BTFSC      STATUS+0, 0
	GOTO       L_Move_Y38
;ACB_2.c,209 :: 		PORTC = PORTC & 0xFB; // Step_Y (RC2) = 0
	MOVLW      251
	ANDWF      PORTC+0, 1
;ACB_2.c,210 :: 		MotorDelay();
	CALL       _MotorDelay+0
;ACB_2.c,211 :: 		PORTC = PORTC | 0x04; // Step_Y (RC2) = 1
	BSF        PORTC+0, 2
;ACB_2.c,212 :: 		MotorDelay();
	CALL       _MotorDelay+0
;ACB_2.c,208 :: 		for (j = 0; j < steps; j++) {
	INCF       Move_Y_j_L0+0, 1
	BTFSC      STATUS+0, 2
	INCF       Move_Y_j_L0+1, 1
;ACB_2.c,213 :: 		}
	GOTO       L_Move_Y37
L_Move_Y38:
;ACB_2.c,215 :: 		PORTE = PORTE | 0x03; // Disable all motors
	MOVLW      3
	IORWF      PORTE+0, 1
;ACB_2.c,216 :: 		}
L_end_Move_Y:
	RETURN
; end of _Move_Y

_Move_D:

;ACB_2.c,218 :: 		void Move_D(unsigned char dir, unsigned int steps) {
;ACB_2.c,220 :: 		if (dir == 0)
	MOVF       FARG_Move_D_dir+0, 0
	XORLW      0
	BTFSS      STATUS+0, 2
	GOTO       L_Move_D40
;ACB_2.c,221 :: 		PORTC = 0x00; // Dir_Y (RC3) = 0, Dir_X (RC1) = 0 (bottom left)
	CLRF       PORTC+0
	GOTO       L_Move_D41
L_Move_D40:
;ACB_2.c,222 :: 		else if (dir == 1)
	MOVF       FARG_Move_D_dir+0, 0
	XORLW      1
	BTFSS      STATUS+0, 2
	GOTO       L_Move_D42
;ACB_2.c,223 :: 		PORTC = 0x02; // Dir_Y (RC3) = 0, Dir_X (RC1) = 1 (bottom right)
	MOVLW      2
	MOVWF      PORTC+0
	GOTO       L_Move_D43
L_Move_D42:
;ACB_2.c,224 :: 		else if (dir == 2)
	MOVF       FARG_Move_D_dir+0, 0
	XORLW      2
	BTFSS      STATUS+0, 2
	GOTO       L_Move_D44
;ACB_2.c,225 :: 		PORTC = 0x08; // Dir_Y (RC3) = 1, Dir_X (RC1) = 0 (top left)
	MOVLW      8
	MOVWF      PORTC+0
	GOTO       L_Move_D45
L_Move_D44:
;ACB_2.c,226 :: 		else if (dir == 3)
	MOVF       FARG_Move_D_dir+0, 0
	XORLW      3
	BTFSS      STATUS+0, 2
	GOTO       L_Move_D46
;ACB_2.c,227 :: 		PORTC = 0x0A; // Dir_Y (RC3) = 1, Dir_X (RC1) = 1 (top right)
	MOVLW      10
	MOVWF      PORTC+0
L_Move_D46:
L_Move_D45:
L_Move_D43:
L_Move_D41:
;ACB_2.c,229 :: 		PORTE = PORTE & 0xFC; // EN_X (RE0) = 0, EN_Y (RE1) = 0 (Enable X & Y motors)
	MOVLW      252
	ANDWF      PORTE+0, 1
;ACB_2.c,231 :: 		for (j = 0; j < steps; j++) {
	CLRF       Move_D_j_L0+0
	CLRF       Move_D_j_L0+1
L_Move_D47:
	MOVF       FARG_Move_D_steps+1, 0
	SUBWF      Move_D_j_L0+1, 0
	BTFSS      STATUS+0, 2
	GOTO       L__Move_D127
	MOVF       FARG_Move_D_steps+0, 0
	SUBWF      Move_D_j_L0+0, 0
L__Move_D127:
	BTFSC      STATUS+0, 0
	GOTO       L_Move_D48
;ACB_2.c,232 :: 		PORTC = PORTC & 0xFA; // Step_X (RC0) = 0, Step_Y (RC2) = 0
	MOVLW      250
	ANDWF      PORTC+0, 1
;ACB_2.c,233 :: 		MotorDelay();
	CALL       _MotorDelay+0
;ACB_2.c,234 :: 		PORTC = PORTC | 0x05; // Step_X (RC0) = 1, Step_Y (RC2) = 1
	MOVLW      5
	IORWF      PORTC+0, 1
;ACB_2.c,235 :: 		MotorDelay();
	CALL       _MotorDelay+0
;ACB_2.c,231 :: 		for (j = 0; j < steps; j++) {
	INCF       Move_D_j_L0+0, 1
	BTFSC      STATUS+0, 2
	INCF       Move_D_j_L0+1, 1
;ACB_2.c,236 :: 		}
	GOTO       L_Move_D47
L_Move_D48:
;ACB_2.c,238 :: 		PORTE = PORTE | 0x03; // Disable all motors
	MOVLW      3
	IORWF      PORTE+0, 1
;ACB_2.c,239 :: 		}
L_end_Move_D:
	RETURN
; end of _Move_D

_Move_Home:

;ACB_2.c,243 :: 		void Move_Home() {
;ACB_2.c,244 :: 		while (1) {
L_Move_Home50:
;ACB_2.c,245 :: 		if (!(PORTB & 0x10) && !(PORTB & 0X20)) { // Both Switches not hit
	BTFSC      PORTB+0, 4
	GOTO       L_Move_Home54
	BTFSC      PORTB+0, 5
	GOTO       L_Move_Home54
L__Move_Home111:
;ACB_2.c,246 :: 		Move_D(0, 300);
	CLRF       FARG_Move_D_dir+0
	MOVLW      44
	MOVWF      FARG_Move_D_steps+0
	MOVLW      1
	MOVWF      FARG_Move_D_steps+1
	CALL       _Move_D+0
;ACB_2.c,247 :: 		} else if (!(PORTB & 0x10)) // RB4 == 0
	GOTO       L_Move_Home55
L_Move_Home54:
	BTFSC      PORTB+0, 4
	GOTO       L_Move_Home56
;ACB_2.c,248 :: 		Move_X(0, 300);
	CLRF       FARG_Move_X_dir+0
	MOVLW      44
	MOVWF      FARG_Move_X_steps+0
	MOVLW      1
	MOVWF      FARG_Move_X_steps+1
	CALL       _Move_X+0
	GOTO       L_Move_Home57
L_Move_Home56:
;ACB_2.c,249 :: 		else if (!(PORTB & 0X20)) // RB5 == 0
	BTFSC      PORTB+0, 5
	GOTO       L_Move_Home58
;ACB_2.c,250 :: 		Move_Y(0, 300);
	CLRF       FARG_Move_Y_dir+0
	MOVLW      44
	MOVWF      FARG_Move_Y_steps+0
	MOVLW      1
	MOVWF      FARG_Move_Y_steps+1
	CALL       _Move_Y+0
	GOTO       L_Move_Home59
L_Move_Home58:
;ACB_2.c,251 :: 		else if ((PORTB & 0x10) && (PORTB & 0x20))
	BTFSS      PORTB+0, 4
	GOTO       L_Move_Home62
	BTFSS      PORTB+0, 5
	GOTO       L_Move_Home62
L__Move_Home110:
;ACB_2.c,252 :: 		break;
	GOTO       L_Move_Home51
L_Move_Home62:
L_Move_Home59:
L_Move_Home57:
L_Move_Home55:
;ACB_2.c,253 :: 		}
	GOTO       L_Move_Home50
L_Move_Home51:
;ACB_2.c,254 :: 		Move_X(1, home_X);
	MOVLW      1
	MOVWF      FARG_Move_X_dir+0
	MOVLW      140
	MOVWF      FARG_Move_X_steps+0
	MOVLW      0
	MOVWF      FARG_Move_X_steps+1
	CALL       _Move_X+0
;ACB_2.c,255 :: 		}
L_end_Move_Home:
	RETURN
; end of _Move_Home

_USART_Init:

;ACB_2.c,257 :: 		void USART_Init() {
;ACB_2.c,258 :: 		SPBRG = 12;   // 9600 Baud Rate
	MOVLW      12
	MOVWF      SPBRG+0
;ACB_2.c,259 :: 		TXSTA = 0x20; // 8-bit, Tx enable, Async, Low speed
	MOVLW      32
	MOVWF      TXSTA+0
;ACB_2.c,260 :: 		RCSTA = 0x90; // SP Enbale, 8-bit, cont. Rx
	MOVLW      144
	MOVWF      RCSTA+0
;ACB_2.c,261 :: 		TRISC = 0x80;
	MOVLW      128
	MOVWF      TRISC+0
;ACB_2.c,262 :: 		PIE1 = PIE1 | 0x20; // RCIE
	BSF        PIE1+0, 5
;ACB_2.c,263 :: 		}
L_end_USART_Init:
	RETURN
; end of _USART_Init

_USART_Tx:

;ACB_2.c,264 :: 		void USART_Tx(char trans) {
;ACB_2.c,265 :: 		while (!(TXSTA & 0x02));
L_USART_Tx63:
	BTFSC      TXSTA+0, 1
	GOTO       L_USART_Tx64
	GOTO       L_USART_Tx63
L_USART_Tx64:
;ACB_2.c,266 :: 		TXREG = trans;
	MOVF       FARG_USART_Tx_trans+0, 0
	MOVWF      TXREG+0
;ACB_2.c,267 :: 		}
L_end_USART_Tx:
	RETURN
; end of _USART_Tx

_Move:
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

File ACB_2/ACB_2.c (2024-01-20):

void msDelay(unsigned int ms);
void Move_X(unsigned char dir, unsigned int steps);
void Move_Y(unsigned char dir, unsigned int steps);
void Move_D(unsigned char dir, unsigned int steps);
void Move(char startx, char starty, char endx, char endy);
void Move_Home();
void USART_Init();
void USART_Tx(char trans);
void Move_motors();
void MotorDelay();
void ATD_init(void);
unsigned char ATD_read(void);
unsigned char read_level();


unsigned int i;
unsigned char level;
unsigned char a;
unsigned int k;
unsigned int tick;
unsigned int step_count;
const unsigned int square_size = 250;
const unsigned int home_x = 140;
unsigned char myRxBuffer[] = "              ";
unsigned char Rx_count = 0;
char txtkp[] = "    ";
char txtlvl[2] = " ";
unsigned char myRxflag = 0;
unsigned char Move_Valid;
unsigned char startx, starty, endx, endy;
unsigned char Move_Type;

sbit LCD_RS at RC4_bit;
sbit LCD_EN at RC5_bit;
sbit LCD_D4 at RA2_bit;
sbit LCD_D5 at RB1_bit;
sbit LCD_D6 at RB2_bit;
sbit LCD_D7 at RB3_bit;

sbit LCD_RS_Direction at TRISC4_bit;
sbit LCD_EN_Direction at TRISC5_bit;
sbit LCD_D4_Direction at TRISA2_bit;
sbit LCD_D5_Direction at TRISB1_bit;
sbit LCD_D6_Direction at TRISB2_bit;
sbit LCD_D7_Direction at TRISB3_bit;

char serial[] = "     ";
char game;

void interrupt(void) {
  if (INTCON & 0x01) {      // PORTB Change interrupt
    if (PORTB & 0x10)       // X_Limit = 1
      PORTE = PORTE | 0x01; // Turn off X axis motor
    else if (PORTB & 0x20)  // Y_Limit = 1
      PORTE = PORTE | 0x02; // Turn off Y axis motor

    INTCON = INTCON & 0xFE; // Clear RBIF
  } else if (PIR1 & 0x20) { // Received data
    myRxBuffer[Rx_count] = RCREG;
    Rx_count++;
    PIR1 = PIR1 & 0xDF;       // Clear RCIF
  } else if (INTCON & 0x04) { // TMRO overflow
    TMR0 = 248;
    tick++;
    INTCON = INTCON & 0xFB;
  }
}

void main() {
  ADCON0 = 0x41;// ATD ON, Don't GO, Channel 0, Fosc/16
  ADCON1 = 0x4E;// A0  Analog, 500 KHz, left justified
  TRISA = 0x01;  // RA2 = D1 (LCD), RA0 = Analog input (Potentiometer)
  TRISB = 0x30;  // RB1-RB3 = D2-D4, RB4 = Switch_X, RB5 = Switch_Y, RB6 and RB7
                 // (not used)
  TRISC = 0x80;  // RC0 = Step_X, RC1 = Dir_X, RC2 = Step_Y, RC3 = Dir_Y, RC4 =
                 // RS, RC5 = E, RC6 = Tx RC7 = Rx
  TRISD = 0x01; // RD0 = Push button
  TRISE = 0x00; // RE0 = EN_X, RE1 = EN_Y (active low), RE2 = Magnet

  PORTC = 0x00;
  PORTE = 0x03;  // Motors OFF
  INTCON = 0xE8; // GIE, RBIE, PEIE, and TMR0IE
  OPTION_REG = 0x87;
  TMR0 = 248;


  Lcd_Init();
  USART_Init();
  Lcd_Cmd(_LCD_CLEAR);      // Clear display
  Lcd_Cmd(_LCD_CURSOR_OFF); // Cursor off
  Move_Home();
  Rx_count = 0;
  while (1) {
    Lcd_Cmd(_LCD_CLEAR);
    Lcd_Out(1, 1, "Welcome to ACBS");
    Lcd_Out(2, 1, "Start?");
    // Wait for start key to be pressed and released
    while (!(PORTD & 0x01));
    USART_Tx('S');

    msDelay(200);
    level = read_level();
    USART_TX(level+'0');

    Lcd_Cmd(_LCD_CLEAR);
    Lcd_Out(1, 1, "Game On");
    game = 1;


    do { // Game is on
      Lcd_Cmd(_LCD_CLEAR);
      Lcd_Out(1, 1, "Enter Move...");
      Rx_Count = 0;
      while (Rx_count != 6);           // Wait for recieval of the Move
      Rx_count = 0; // Reset rx counter
      Move_Valid = myRXBuffer[0];
      startx = myRxBuffer[1];
      starty = myRxBuffer[2];
      Move_Type = myRxBuffer[3];
      endx = myRxBuffer[4];
      endy = myRxbuffer[5];

      if (Move_Valid == 'L') { // Move is legal
        Lcd_Cmd(_LCD_CLEAR);
        Lcd_Out(1, 1, "Player Moving...");
        Move_motors();
        USART_Tx('D');
      }

      else if (Move_Valid == 'M') {
        // Display player wins
        Lcd_Cmd(_LCD_CLEAR);
        Lcd_Out(1, 1, "Game ended");
        Lcd_Out(2, 1, "Player wins");
        game = 0;
        break;
      }
      Rx_Count = 0;
      while (Rx_count != 6);           // Wait to recieve engine move
      Rx_count = 0; // reset counter
      Move_Valid = myRXBuffer[0];
      startx = myRxBuffer[1];
      starty = myRxBuffer[2];
      Move_Type = myRxBuffer[3];
      endx = myRxBuffer[4];
      endy = myRxbuffer[5];

      if (Move_Valid == 'E'){
        Lcd_Cmd(_LCD_CLEAR);
        Lcd_Out(1, 1, "Engine Moving...");
        Move_motors();
        USART_Tx('D');
      }

      else if (Move_Valid == 'M') {
        // Display Engine wins
        Lcd_Cmd(_LCD_CLEAR);
        Lcd_Out(1, 1, "Game ended");
        Lcd_Out(2, 1, "Engine wins");
        game = 0;
        break;
      }
    } while (game);
    msDelay(60000); // Wait one minute
  }
}

void msDelay(unsigned int ms) {
  tick = 0;
  while (tick < ms)
    ;
}

void MotorDelay() {
  for (a = 0; a < 200; a++)
    ;
}


void Move_X(unsigned char dir, unsigned int steps) {
  unsigned int j;
  if (dir)
    PORTC = 0x02; // Dir_X (RC1) = 1 (right)
  else
    PORTC = 0x00; // Dir_X (RC1) = 0 (left)

  PORTE = PORTE & 0xFE; // EN_X (RE0) = 0 (Enable X motor)

  for (j = 0; j < steps; j++) {
    PORTC = PORTC & 0xFE; // Step_X (RC0) = 0
    MotorDelay();
    PORTC = PORTC | 0x01; // Step_X (RC0) = 1
    MotorDelay();
  }

  PORTE = PORTE | 0x03; // Disable all motors
}

void Move_Y(unsigned char dir, unsigned int steps) {
  unsigned int j;
  if (dir)
    PORTC = 0x08; // Dir_Y (RC3) = 1 (up)
  else
    PORTC = 0x00; // Dir_Y (RC3) = 0 (down)

  PORTE = PORTE & 0xFD; // EN_Y (RE1) = 0 (Enable Y motor)

  for (j = 0; j < steps; j++) {
    PORTC = PORTC & 0xFB; // Step_Y (RC2) = 0
    MotorDelay();
    PORTC = PORTC | 0x04; // Step_Y (RC2) = 1
    MotorDelay();
  }

  PORTE = PORTE | 0x03; // Disable all motors
}

void Move_D(unsigned char dir, unsigned int steps) {
  unsigned int j;
  if (dir == 0)
    PORTC = 0x00; // Dir_Y (RC3) = 0, Dir_X (RC1) = 0 (bottom left)
  else if (dir == 1)
    PORTC = 0x02; // Dir_Y (RC3) = 0, Dir_X (RC1) = 1 (bottom right)
  else if (dir == 2)
    PORTC = 0x08; // Dir_Y (RC3) = 1, Dir_X (RC1) = 0 (top left)
  else if (dir == 3)
    PORTC = 0x0A; // Dir_Y (RC3) = 1, Dir_X (RC1) = 1 (top right)

  PORTE = PORTE & 0xFC; // EN_X (RE0) = 0, EN_Y (RE1) = 0 (Enable X & Y motors)

  for (j = 0; j < steps; j++) {
    PORTC = PORTC & 0xFA; // Step_X (RC0) = 0, Step_Y (RC2) = 0
    MotorDelay();
    PORTC = PORTC | 0x05; // Step_X (RC0) = 1, Step_Y (RC2) = 1
    MotorDelay();
  }

  PORTE = PORTE | 0x03; // Disable all motors
}

// Move to the bottom left (home position, a1) untill switch is pressed
// (interrupt)
void Move_Home() {
  while (1) {
    if (!(PORTB & 0x10) && !(PORTB & 0X20)) { // Both Switches not hit
      Move_D(0, 300);
    } else if (!(PORTB & 0x10)) // RB4 == 0
      Move_X(0, 300);
    else if (!(PORTB & 0X20)) // RB5 == 0
      Move_Y(0, 300);
    else if ((PORTB & 0x10) && (PORTB & 0x20))
      break;
  }
  Move_X(1, home_X);
}

void USART_Init() {
  SPBRG = 12;   // 9600 Baud Rate
  TXSTA = 0x20; // 8-bit, Tx enable, Async, Low speed
  RCSTA = 0x90; // SP Enbale, 8-bit, cont. Rx
  TRISC = 0x80;
  PIE1 = PIE1 | 0x20; // RCIE
}
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

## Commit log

2024-01-20 MicroC code
    [MyProject.cfg]
2024-01-20 Flow Chart
